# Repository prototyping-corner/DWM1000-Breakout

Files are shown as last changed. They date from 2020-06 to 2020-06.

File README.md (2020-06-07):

# DWM1000 Breakout
  
This breakout is for the Decawave DWM1000 module in a breadboard friendly form factor with onboard logic level converter and status LED's. The DWM1000 is an IEEE802.15.4-2011 UWB compliant wireless module capable of precision indoor positioning and high data rates, making it perfect for projects that require localization where GPS may not be available or suitable.  
  
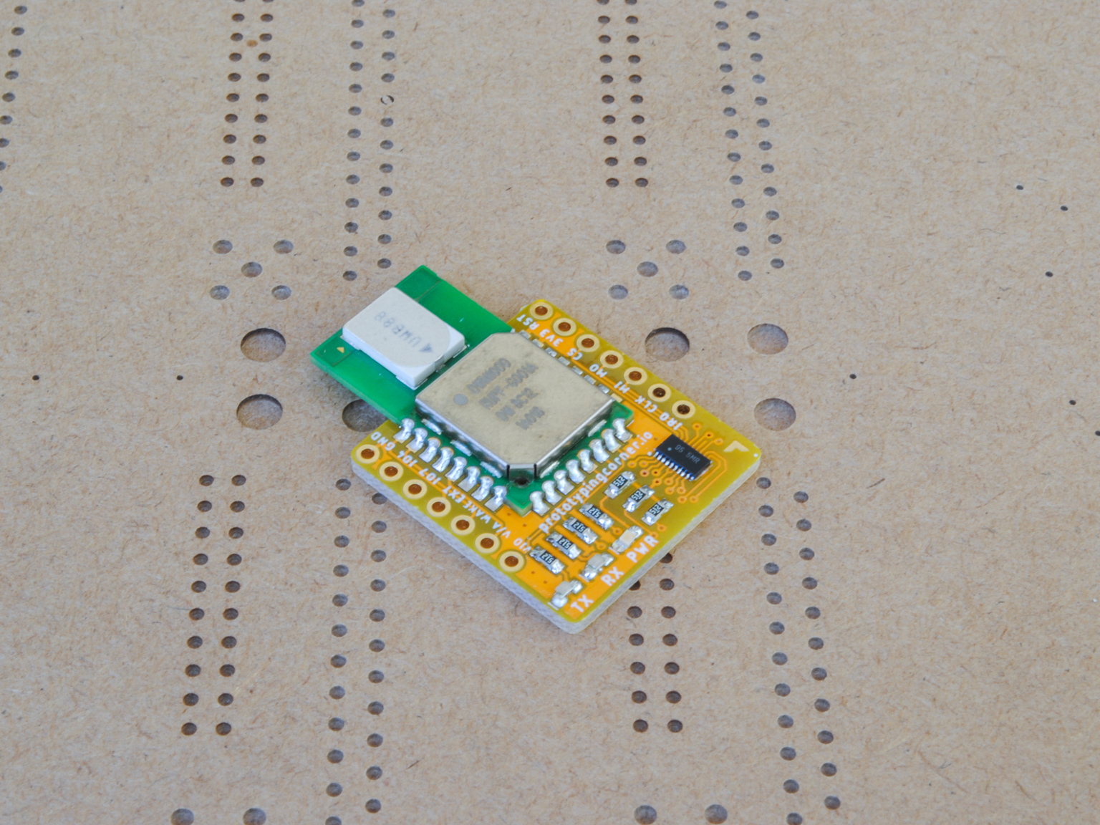
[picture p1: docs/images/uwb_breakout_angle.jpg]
Boards
  
  
**Features:**  
– Decawave DWM1000 for precision tracking  
– Breadboard friendly form-factor  
– Connect to your micro of choice  
– Operate over 1.65 - 5.5 volt range with built-in logic level converter  
– Resistors and solder bridge pads for setting SPI phase and polarities  
– Exposed pads for SFD and ROK LEDs  
  
Open source hardware licensed [under the CERN OHL v1.2](https://github.com/prototyping-corner/DWM1000-Breakout/blob/master/LICENSE)  
Documentation licensed under [Creative Commons Attribution-ShareAlike 4.0](https://creativecommons.org/licenses/by-sa/4.0/)

**More information:**  
– [Decawave DW1000 datasheet](https://www.decawave.com/sites/default/files/resources/dwm1000-datasheet-v1.3.pdf)  
– [Decawave Application Notes](https://www.decawave.com/application-notes/)  
  
Purchase from [Tindie]() (coming soon)  
Usage documentation coming soon

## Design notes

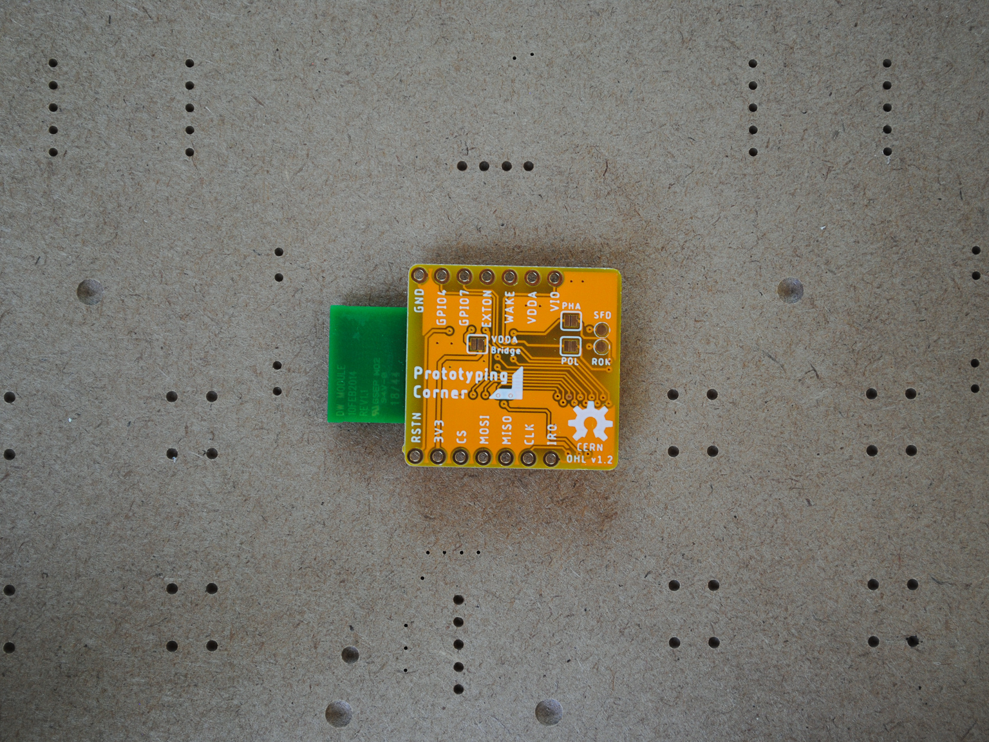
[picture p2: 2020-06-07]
docs/images/uwb_breakout_bottom.jpg

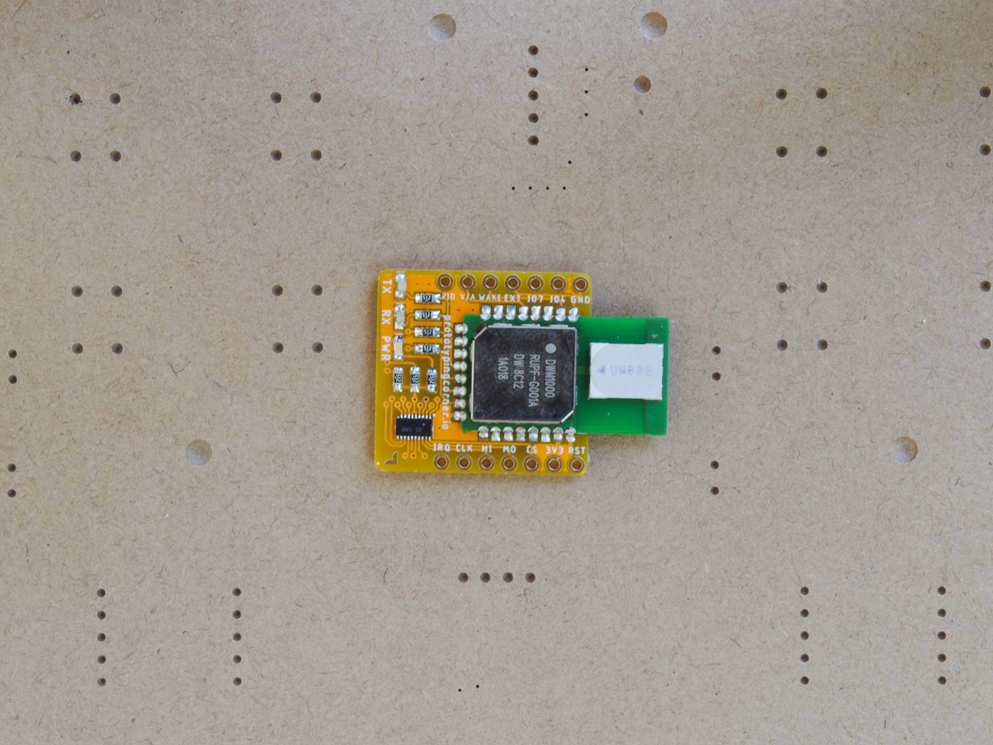
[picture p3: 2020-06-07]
docs/images/uwb_breakout_top.jpg

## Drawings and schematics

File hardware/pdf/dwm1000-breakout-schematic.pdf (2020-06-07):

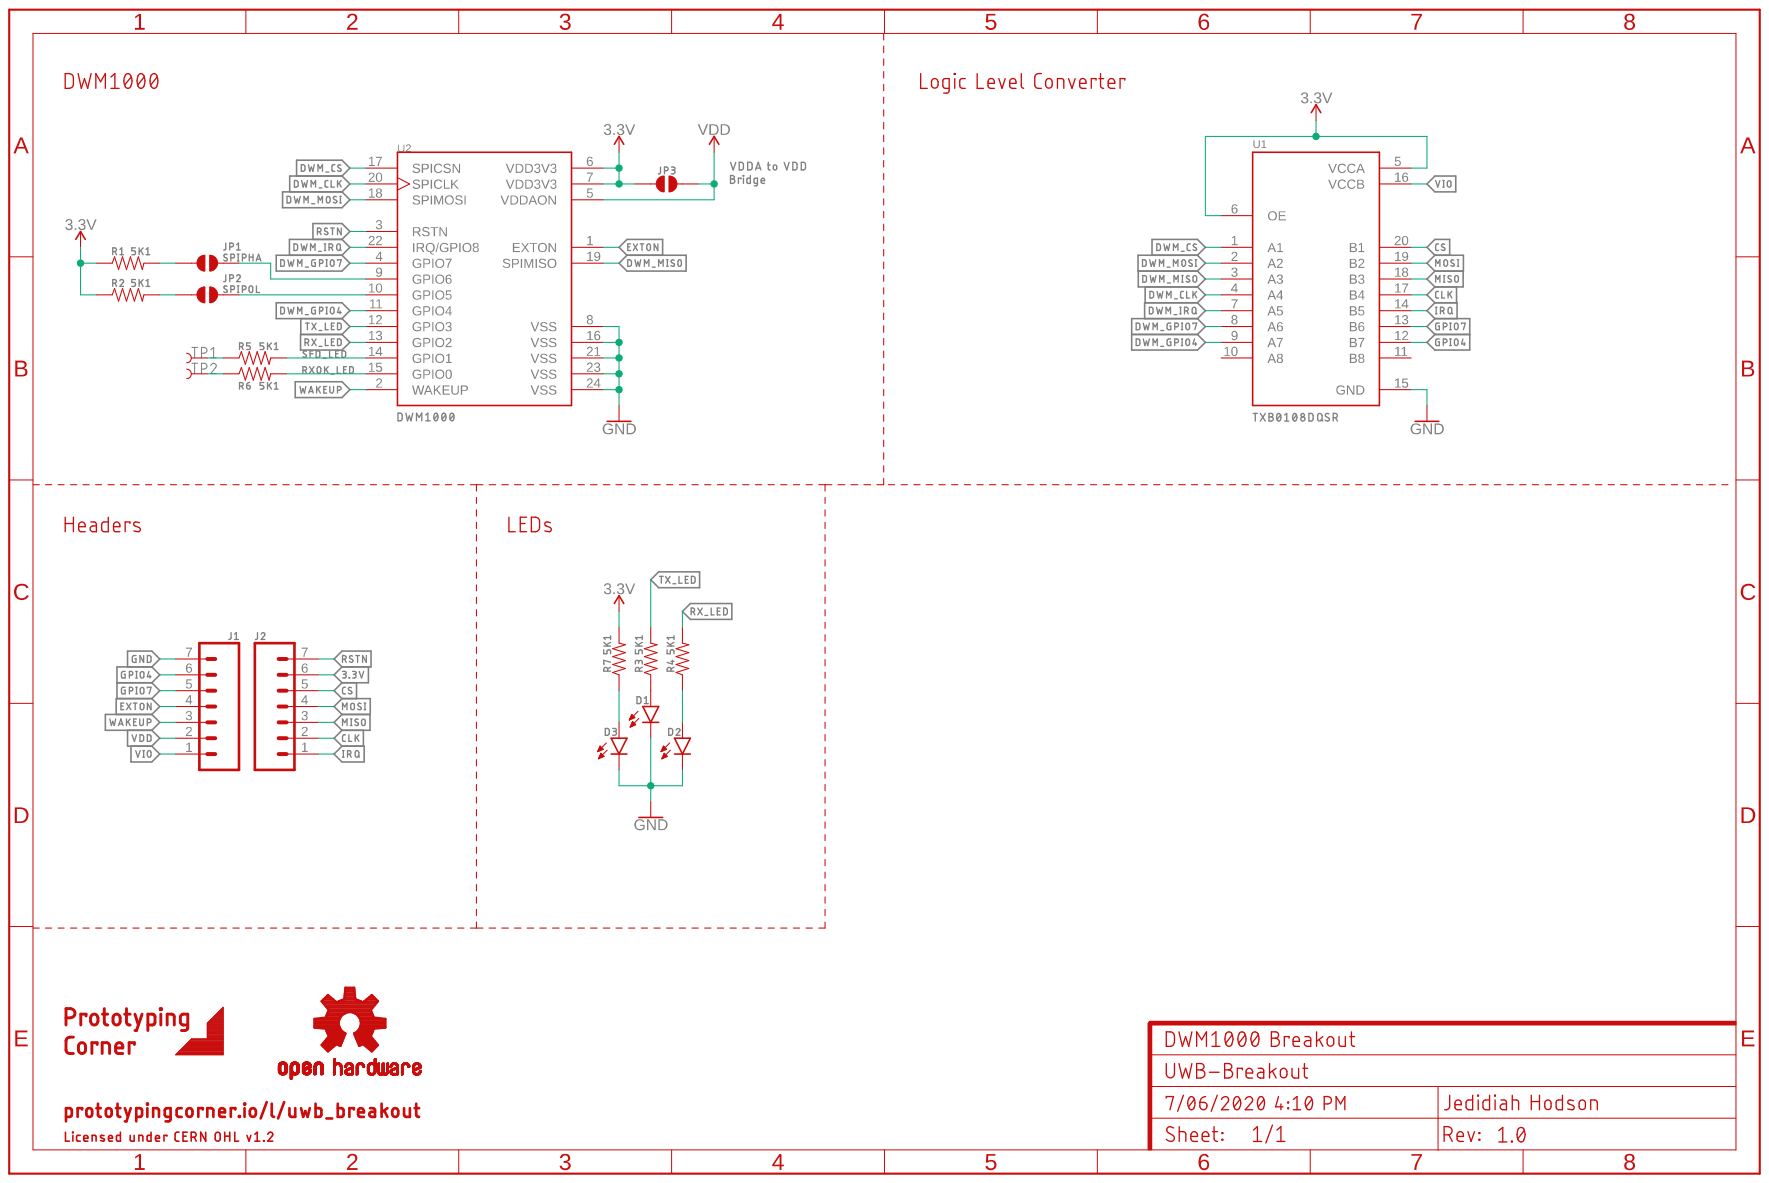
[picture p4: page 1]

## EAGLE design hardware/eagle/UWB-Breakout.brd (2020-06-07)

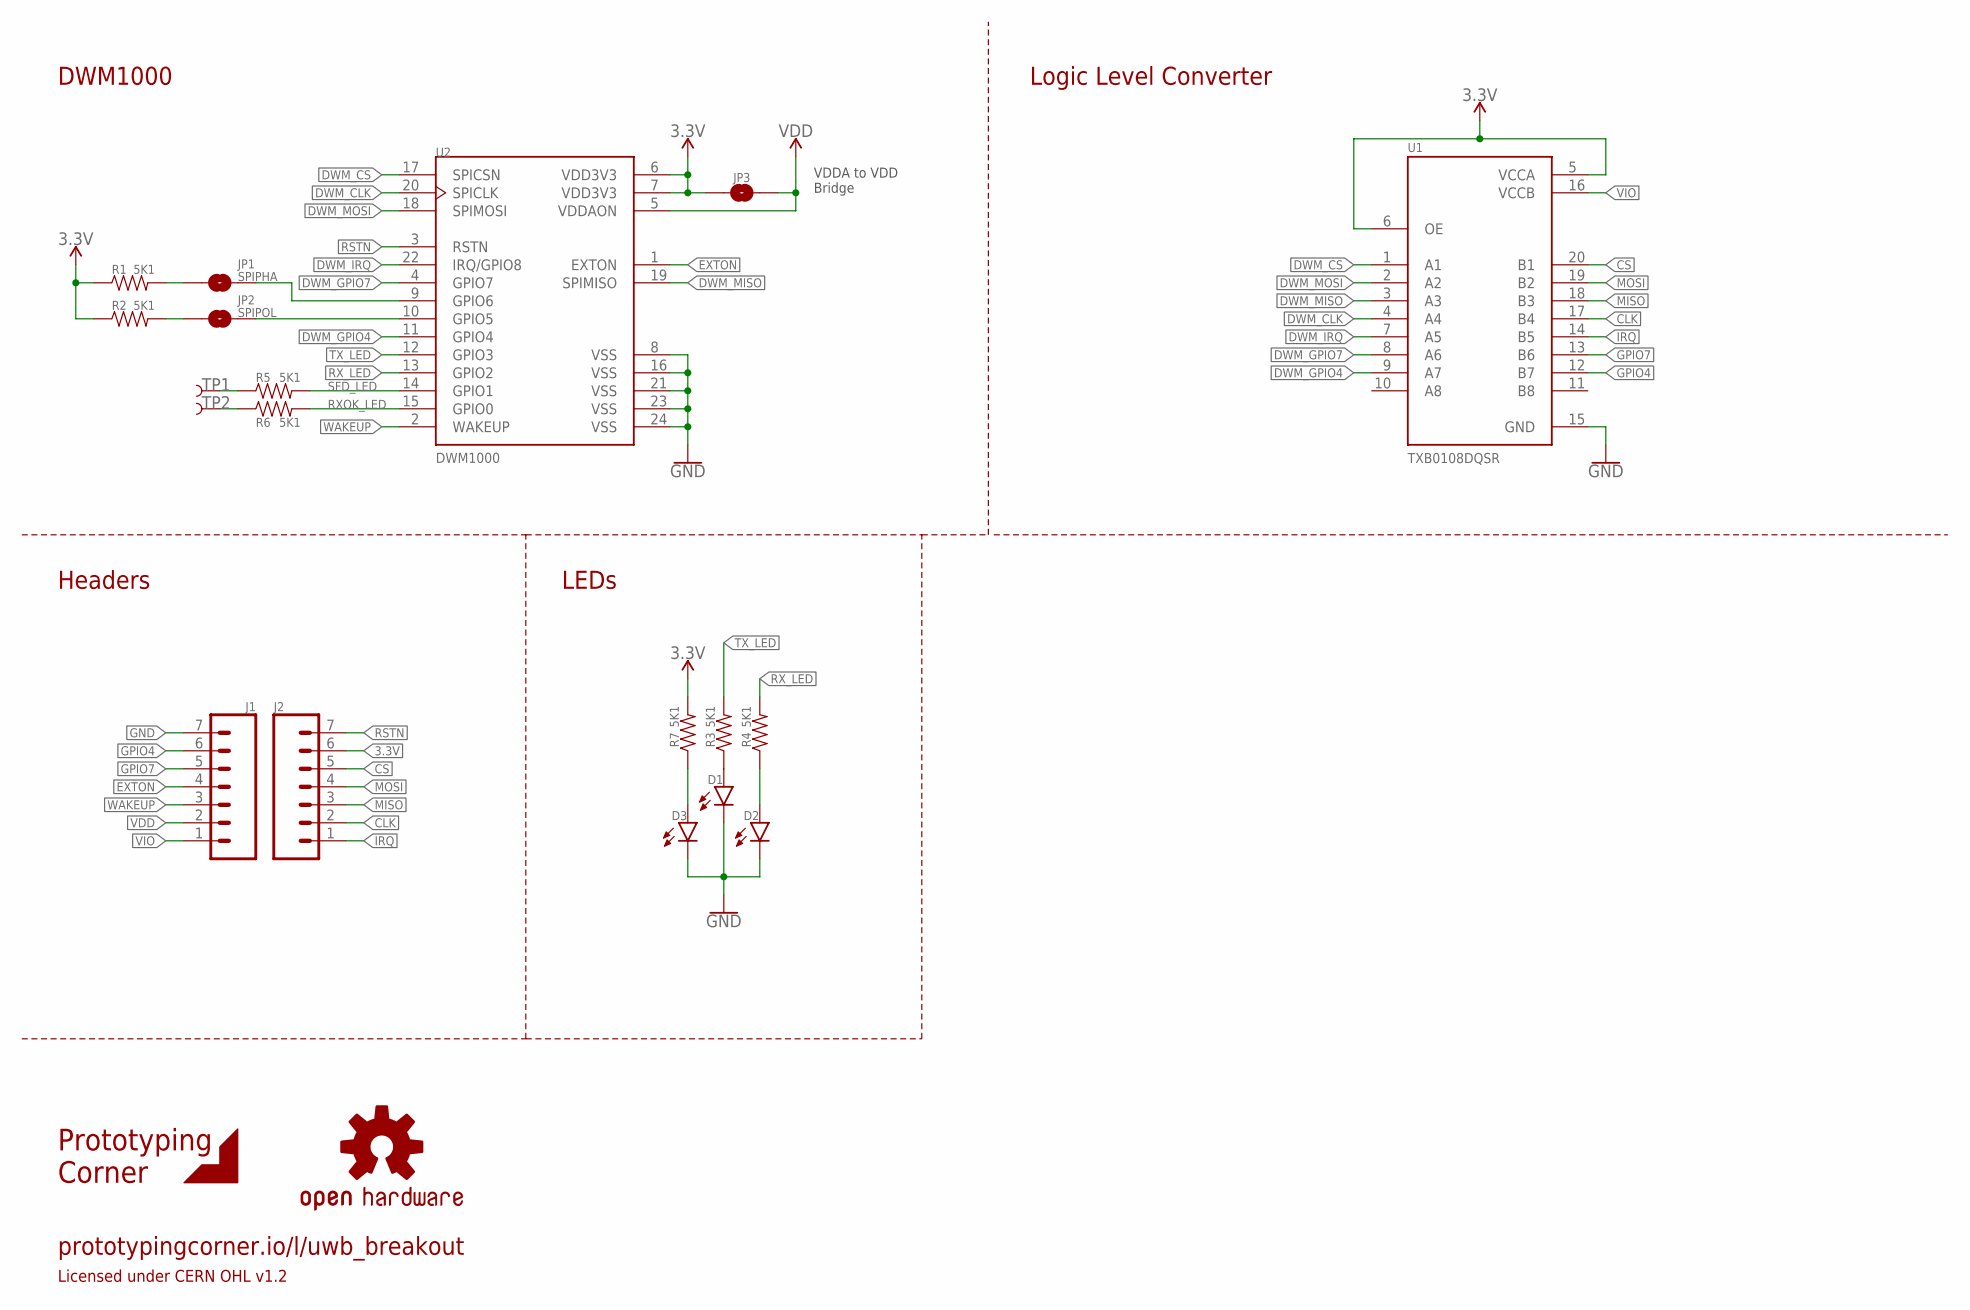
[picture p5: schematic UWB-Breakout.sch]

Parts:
D1: Yellow; LED-0603
D2: GREEN; LED-0603
D3: BLUE; LED-0603
J1, J2: CONN_07NO_SILK; 1X07_NO_SILK
JP1: SPIPHA; SMT-JUMPER_2_NO_SILK
JP2: SPIPOL; SMT-JUMPER_2_NO_SILK
JP3: JUMPER-SMT_2_NO_SILK; SMT-JUMPER_2_NO_SILK
LOGO1: OSHW-LOGOM; OSHW-LOGO-M
R1, R2, R3, R4, R5, R6, R7: 5K1; 0603
TP1, TP2: TEST-POINT3X5; PAD.03X.05
U1: TXB0108DQSR; SON40P400X200X55-20N
U2: DWM1000; XCVR_DWM1000

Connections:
3.3V: J2.6, JP3.1, R1.1, R2.1, R7.2, U1.5 (VCCA), U1.6 (OE), U2.6 (VDD3V3), U2.7 (VDD3V3)
CLK: J2.2, U1.17 (B4)
CS: J2.5, U1.20 (B1)
DWM_CLK: U1.4 (A4), U2.20 (SPICLK)
DWM_CS: U1.1 (A1), U2.17 (SPICSN)
DWM_GPIO4: U1.9 (A7), U2.11 (GPIO4)
DWM_GPIO7: U1.8 (A6), U2.4 (GPIO7)
DWM_IRQ: U1.7 (A5), U2.22 (IRQ/GPIO8)
DWM_MISO: U1.3 (A3), U2.19 (SPIMISO)
DWM_MOSI: U1.2 (A2), U2.18 (SPIMOSI)
EXTON: J1.4, U2.1 (EXTON)
GND: D1.C, D2.C, D3.C, J1.7, U1.15 (GND), U2.8 (VSS), U2.16 (VSS), U2.21 (VSS), U2.23 (VSS), U2.24 (VSS)
GPIO4: J1.6, U1.12 (B7)
GPIO7: J1.5, U1.13 (B6)
IRQ: J2.1, U1.14 (B5)
MISO: J2.3, U1.18 (B3)
MOSI: J2.4, U1.19 (B2)
unnamed: D3.A, R7.1
unnamed: D1.A, R3.1
unnamed: JP1.2, U2.9 (GPIO6)
unnamed: JP2.2, U2.10 (GPIO5)
unnamed: JP1.1, R1.2
unnamed: JP2.1, R2.2
unnamed: R6.1, TP2.P$1
unnamed: R5.1, TP1.P$1
unnamed: D2.A, R4.1
RSTN: J2.7, U2.3 (RSTN)
RXOK_LED: R6.2, U2.15 (GPIO0)
RX_LED: R4.2, U2.13 (GPIO2)
SFD_LED: R5.2, U2.14 (GPIO1)
TX_LED: R3.2, U2.12 (GPIO3)
VDD: J1.2, JP3.2, U2.5 (VDDAON)
VIO: J1.1, U1.16 (VCCB)
WAKEUP: J1.3, U2.2 (WAKEUP)

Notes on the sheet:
Prototyping Corner
prototypingcorner.io/l/uwb_breakout
Licensed under CERN OHL v1.2
VDDA to VDD Bridge
Headers
DWM1000
Logic Level Converter
LEDs

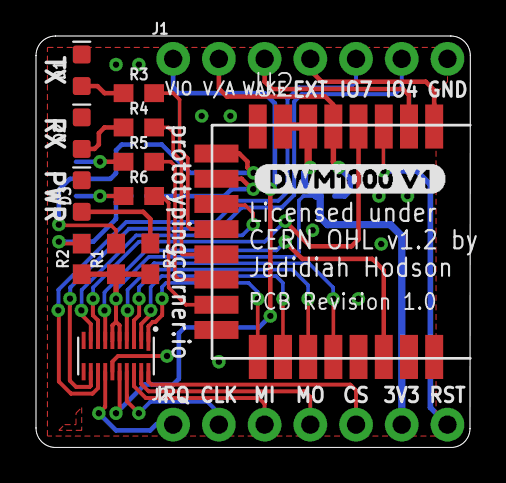
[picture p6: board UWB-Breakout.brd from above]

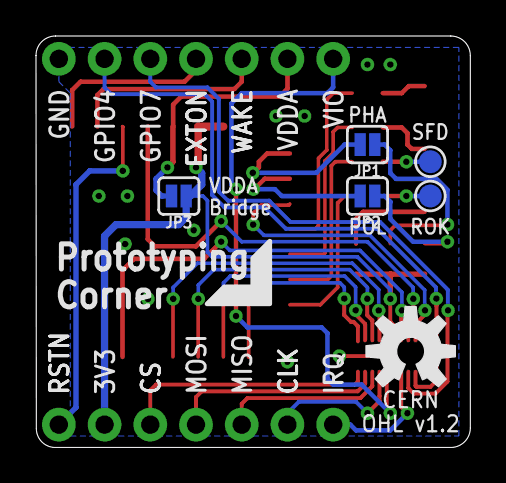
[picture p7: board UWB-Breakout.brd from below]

Board: 2 copper layers, 24.1 x 22.9 mm, 21 parts (6 on the bottom side), 34 nets.

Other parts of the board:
U$1: DWM1000_V10

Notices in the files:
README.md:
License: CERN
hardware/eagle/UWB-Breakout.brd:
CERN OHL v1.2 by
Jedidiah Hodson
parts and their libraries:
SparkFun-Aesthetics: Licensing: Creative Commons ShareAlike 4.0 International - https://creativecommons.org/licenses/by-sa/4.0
